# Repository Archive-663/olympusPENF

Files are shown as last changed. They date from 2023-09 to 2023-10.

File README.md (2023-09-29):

# Lot no. 007 | Accessories for the Olympus PEN-F half frame SLR

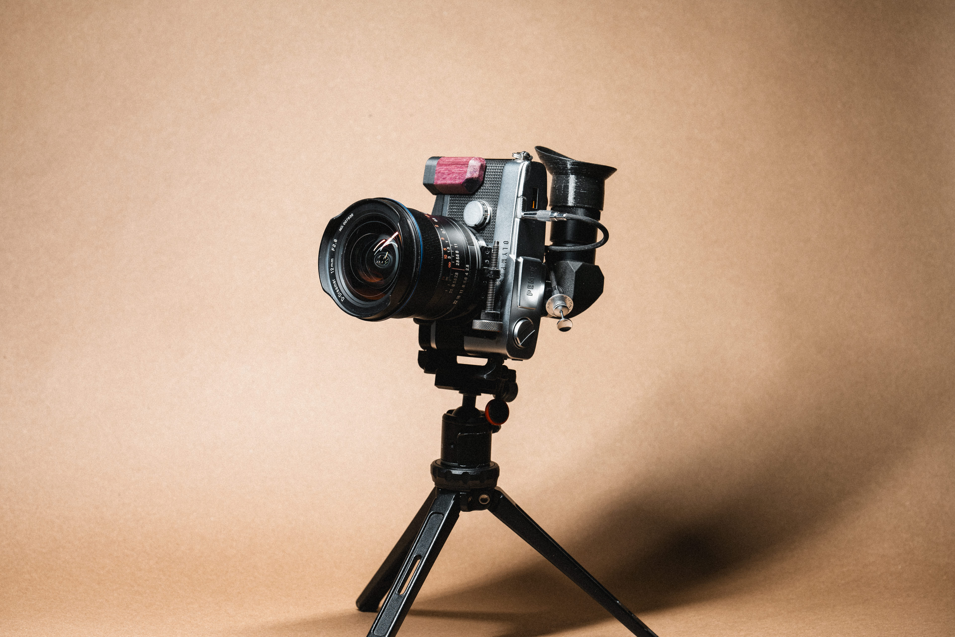
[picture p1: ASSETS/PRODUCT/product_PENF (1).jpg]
productShot001


### In this repository:
- [Pen-F L-Bracket + Grip](https://github.com/Archive-663/olympusPENF/tree/main/L-Bracket)
- [Pen-F baseModel](https://github.com/Archive-663/olympusPENF/tree/main/baseBody)

### Background Story:
The L-Bracket was designed because I needed a more reliable system for testing and using my [shift adapters](https://github.com/Archive-663/lensAdapters/tree/main/Olympus%20PEN-F). I picked up a broken PEN-FT as well to make sure the L-Bracket would be compatible with most of the PEN-F cameras. It's unconfirmed on the PEN-FV, but I think it has the same mounting point as th e PEN-FT. I modeled a similar ECG-4 type grip from the new Digital Pen-F and you also have the ability to make your own custom wood grips.

I've enjoyed using the L-Brackt + Grip on my own PEN-F. It only adds a little heft too body but it fits better in my hand now. You can run it without the Grip or the Side bracket but on the PEN-F the mounting point kind of make it a little wonky to use with just the Base Bracket. 

### Help support Archive 663 with a dontation or monthly sub



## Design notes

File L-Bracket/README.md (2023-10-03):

## L-Bracket with Grip for Olympus PEN-F & FT (FV unconfirmed)

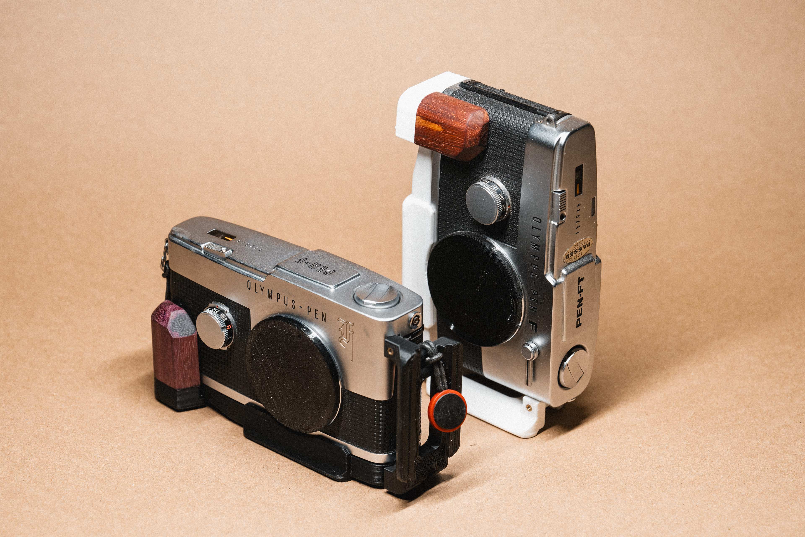
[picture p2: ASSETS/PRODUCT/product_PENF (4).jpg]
olympusPENFLBracket


### Features:
- 60mm Arca-Swiss compatible rail.
- Customizable & Removeable Grip.
- Camera Strap Loop.
- Two point connection system for maximum security.

### What you'll need:
- 1x 1/4-20 x 5/16" hex drive pan head screw
- 1x 1/4-20 x 17mm Camvate Tripod Screw (Item no. 1987)
- 1x M4 x 12mm Hex Cap Machine Screw
- 1x M4 x 8mm Heatset Threaded Insert
- 1x M2 x 8mm Hex Cap Machine Screw
- 1x M2 x 4mm Heatset Threaded Insert
- 1x Soldering Iron or Heat Set Insert Jig
- 8" Bastard Cut file
- Assortment of mini files

### What would be helpful:
- M2 drill bit
- M2.6 drill bit
- M4 drill bit
- M5.3 drill bit
- 1/4 drill bit

### What you'll need if you want to make a custom grip
- 2x M4 x 18mm Hex Cap Machine Screw
- 2x M4 Threaded Inserts for wood
- A stationary belt or disc sander
- A hand saw
- M5.5 drill bit for the threaded inserts
- Video coming soon.

### Printing help:
Filament recommendation:
- ABS

Normally, I would recommend PETG but it's pretty bad with impacts.

Generally, all my designs have chamfers on the print face of the STL. You can reference the supplied 'printOrientation' .3mf files for suggested print orientation.

### Assembly help:
Drill holes to their correct tap size before tapping.
- M4 heatset inserts require M5.3 bore.
- M2 heatset inserts require M2.6 bore.

You will need to file the Sliding Arm so it slides smoothly in the Base Bracket. Additionally, you will need to file the dove tail on the Side Bracket for a snug fit in the Sliding Arm.

You may need to clean up the M2 hole after heat setting the threaded insert.

### Help support Archive 663 with a dontation or monthly sub



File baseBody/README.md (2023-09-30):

## baseBody_PENF

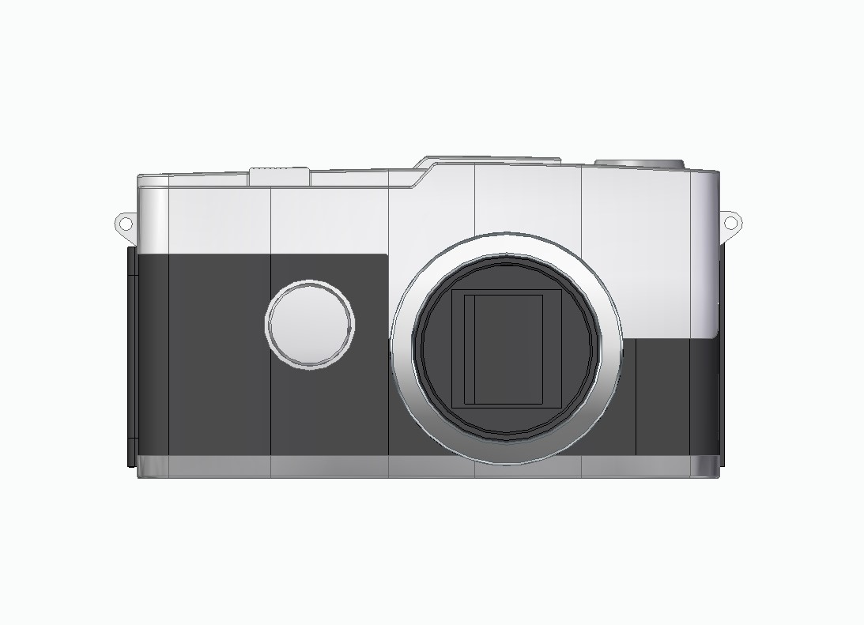
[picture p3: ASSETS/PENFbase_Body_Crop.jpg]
baseBody_PENF


### Making your own accessories:
I've included my own drafted PEN-F body with both PEN-F and PEN-FT tripod attachment points. Measurements are based on both my F and FT. I've had to use my best judgement to interpret what the Olympus designers were thinking in the 60's when they were designing the PEN-F. It's as close as I think I can get it to a real PEN-F. And I believe it's a very good starting point if you want to make your own Pen-F asscessories. 

There are some issues with real world PEN-F and PEN-FTs. The base isn't flat; there's a slight curve. Over the decades the camera strap loops may have been damaged and are no longer aligned to where they once were installed.

### Help support Archive 663 with a dontation or monthly sub



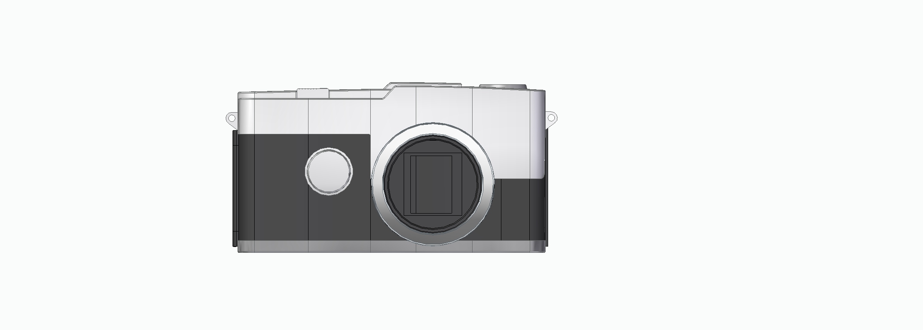
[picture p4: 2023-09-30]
ASSETS/PENFbase_Body.jpg

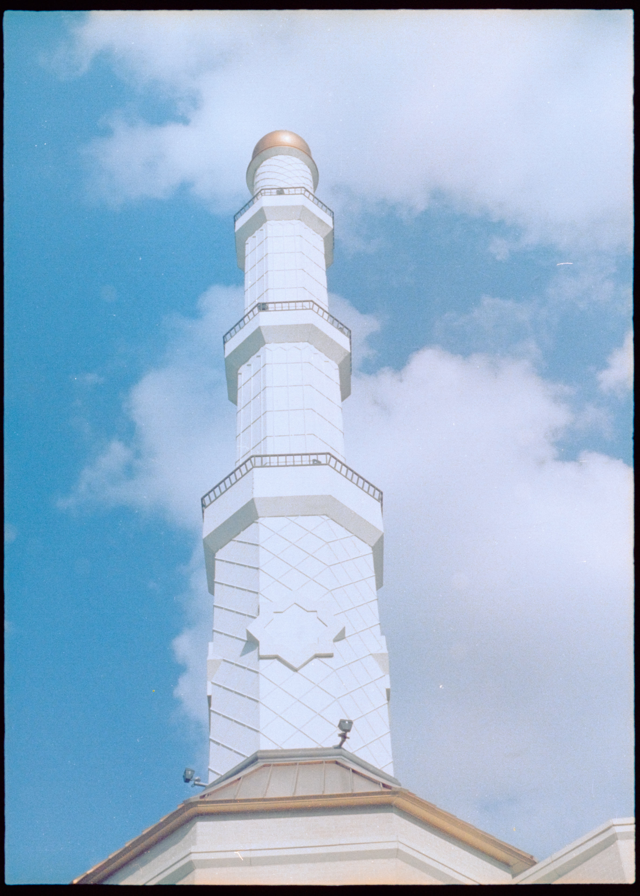
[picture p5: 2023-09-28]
ASSETS/PHOTO/samplePOS_PENF (4).jpg

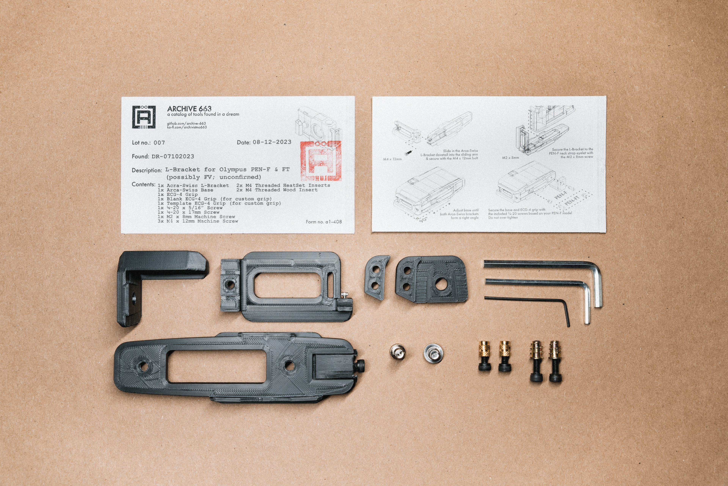
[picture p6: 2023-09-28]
ASSETS/PRODUCT/product_PENF (7).jpg

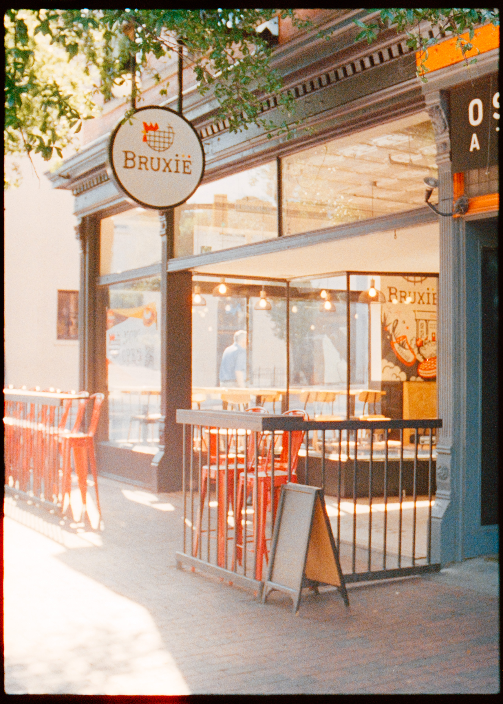
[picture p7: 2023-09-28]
ASSETS/PHOTO/samplePOS_PENF (42).jpg

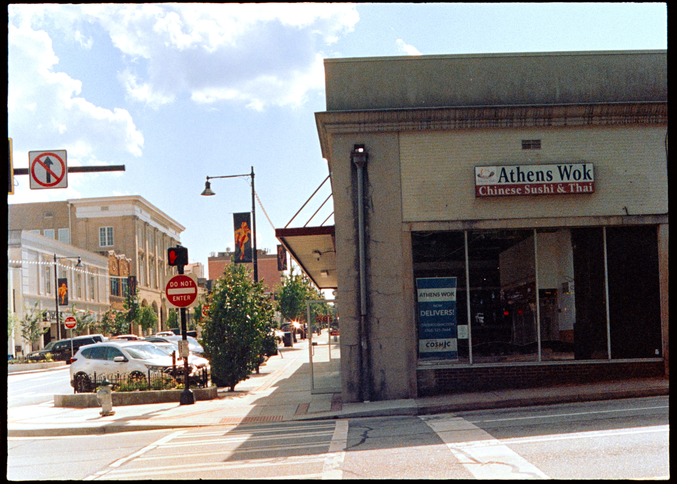
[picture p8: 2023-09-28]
ASSETS/PHOTO/samplePOS_PENF (30).jpg

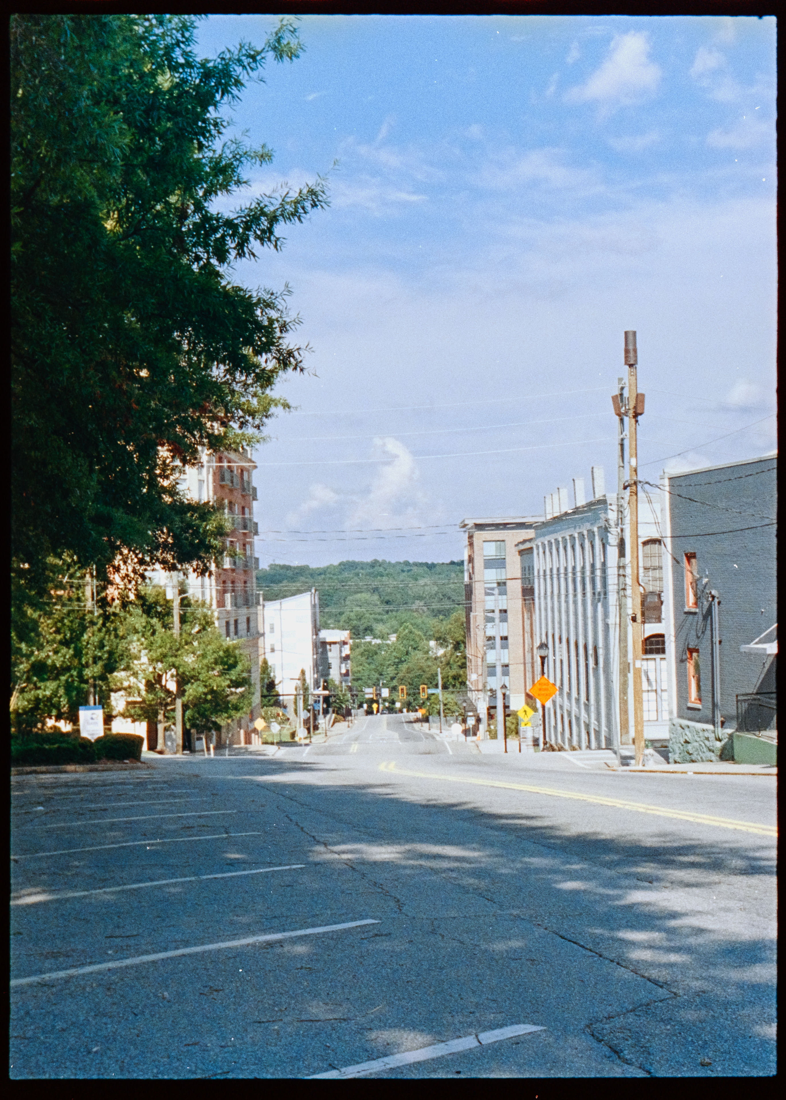
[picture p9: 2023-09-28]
ASSETS/PHOTO/samplePOS_PENF (39).jpg

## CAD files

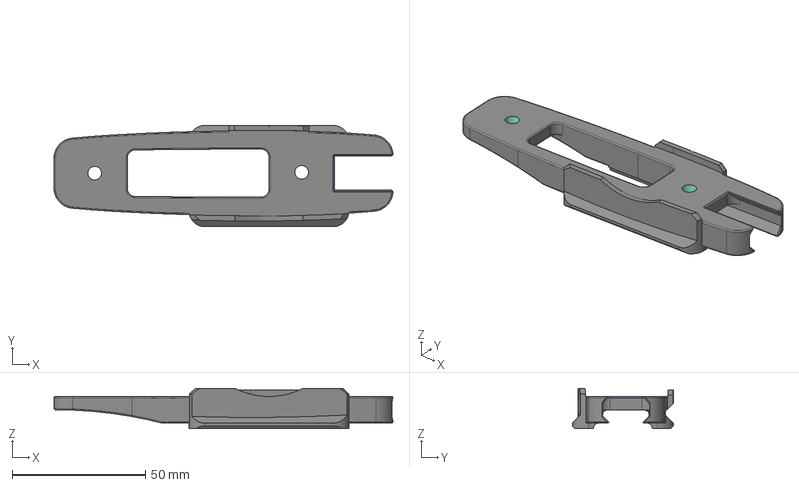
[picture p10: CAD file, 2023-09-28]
L-Bracket/STEP/baseMainBracket_PENF.stp
127.1 x 38.0 x 15.0 mm

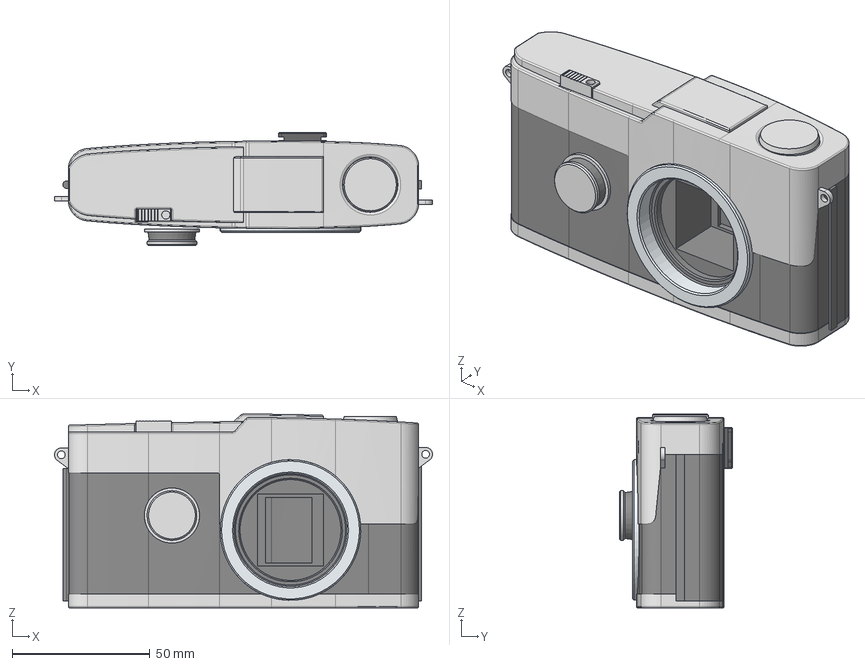
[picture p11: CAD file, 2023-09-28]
baseBody/baseBody_PENF.stp
137.1 x 41.1 x 70.3 mm
Olympus PENF Model
Olympus PENF Model Winder
Olympus PENF Model Film Door

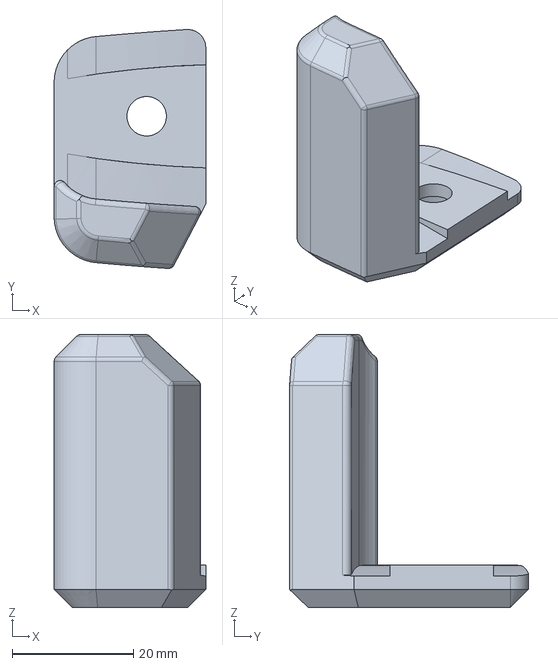
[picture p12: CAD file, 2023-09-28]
L-Bracket/STEP/baseGrip_PENF.stp
25.0 x 39.4 x 45.0 mm

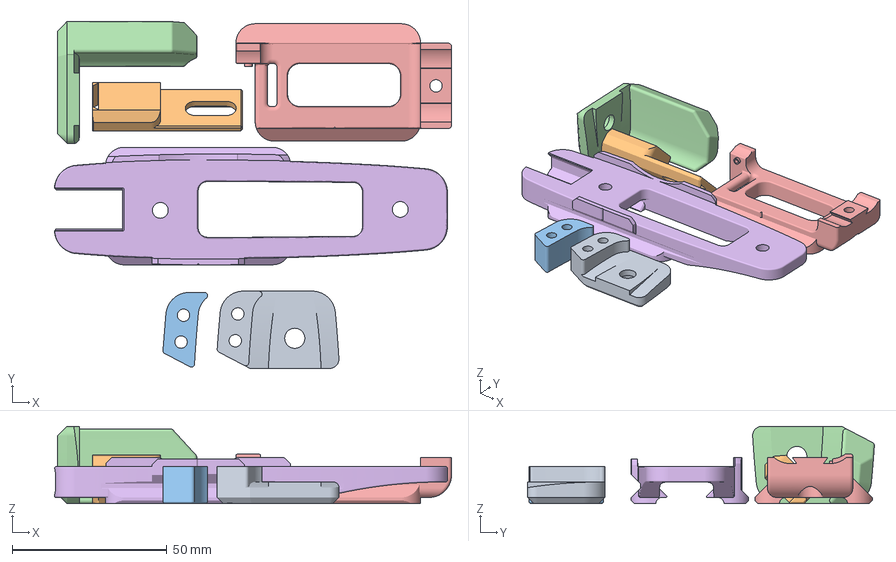
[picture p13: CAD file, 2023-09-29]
L-Bracket/STL/printOrientation_baseLBracket_PENF.3mf
128.4 x 112.2 x 25.0 mm
baseBlankGrip_PENF.stl
baseSlidingArm_PENF.stl
baseTemplateGrip_PENF.stl
baseGrip_PENF.stl
baseSideBracket_PENF.stl
baseMainBracket_PENF.stl

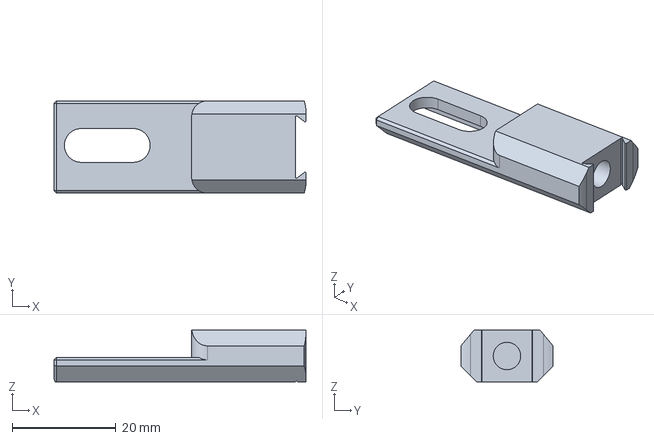
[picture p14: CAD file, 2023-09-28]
L-Bracket/STEP/baseSlidingArm_PENF.stp
48.5 x 17.8 x 10.00 mm

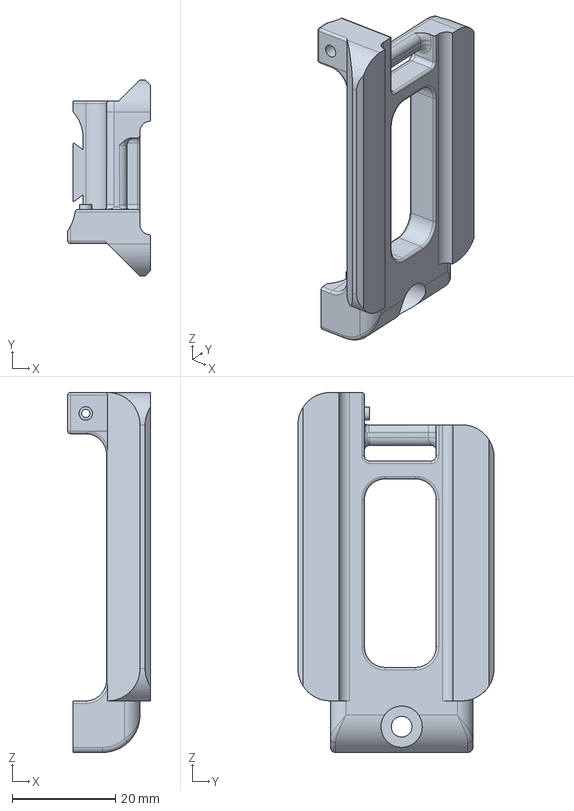
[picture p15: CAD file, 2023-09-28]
L-Bracket/STEP/baseSideBracket_PENF.stp
16.0 x 38.0 x 69.8 mm

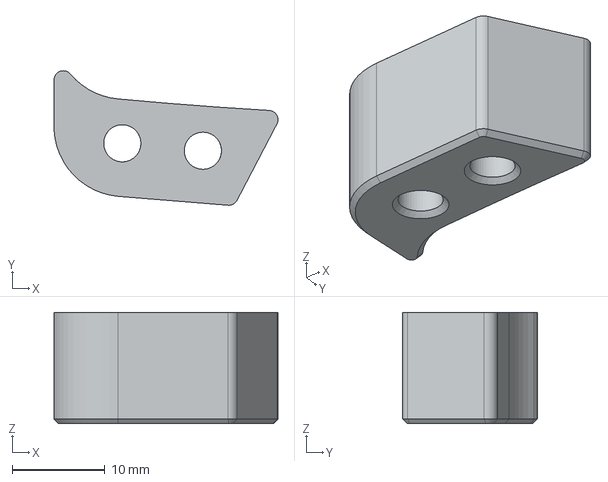
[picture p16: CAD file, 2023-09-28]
L-Bracket/STEP/baseTemplateGrip_PENF.stp
24.1 x 14.5 x 12.0 mm

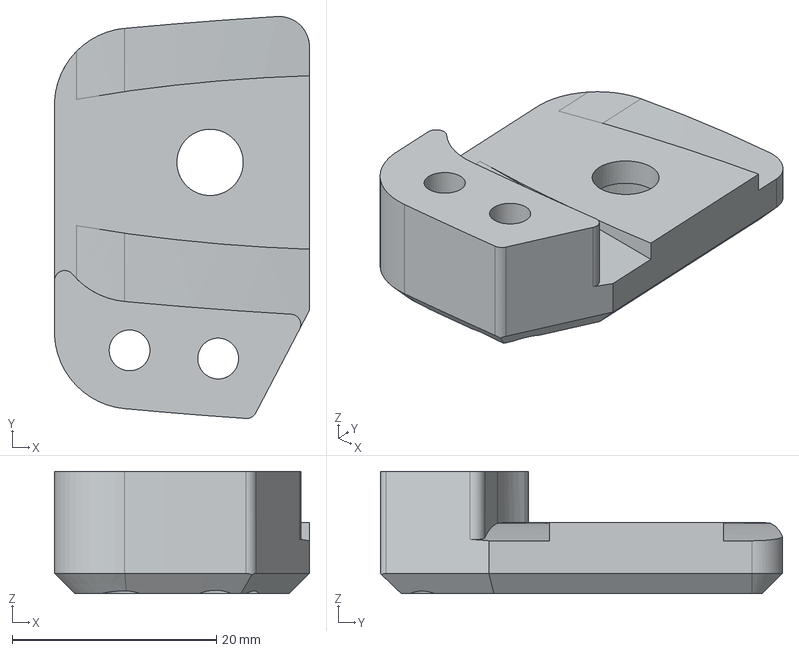
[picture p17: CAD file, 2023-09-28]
L-Bracket/STEP/baseBlankGrip_PENF.stp
25.0 x 39.4 x 12.0 mm

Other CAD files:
L-Bracket/STL/baseBlankGrip_PENF.stl
L-Bracket/STL/baseGrip_PENF.stl
L-Bracket/STL/baseMainBracket_PENF.stl
L-Bracket/STL/baseSideBracket_PENF.stl
L-Bracket/STL/baseSlidingArm_PENF.stl
L-Bracket/STL/baseTemplateGrip_PENF.stl

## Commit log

2023-09-28 Upload image Assets
    [baseBlankGrip_PENF.stl, baseBlankGrip_PENF.stp, baseBody_PENF.stp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]
2023-09-29 Upload printOrientation file
    [printOrientation_baseLBracket_PENF.3mf]
